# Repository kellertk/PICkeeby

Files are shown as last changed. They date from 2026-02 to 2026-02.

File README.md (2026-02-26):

# PICkeeby

PS/2 Keyboard/Mouse Controller for Homebrew Computers

## Overview

PICkeeby emulates an i8042 keyboard controller, bridging PS/2 devices to a host
computer's I/O bus. It supports both 6502 and Z80 bus timing via a mode jumper,
and handles two PS/2 ports (keyboard and mouse) simultaneously.

The name is a nod to PIC's origin as "Peripheral Interface Controller" -- using
a small microcontroller for I/O duties is a time-honored tradition in computer
design.

## Hardware

- **MCU:** PIC16F18344 at 32 MHz (internal oscillator)
- **GAL:** ATF22V10C for address decoding, status flags (OBF/IBF), A0
  registration, and IRQ generation
- **Latches:** 74AHCT574 (output) and 74AHCT373 (input) for bus interfacing
- **Inverter:** 74AHCT1G14 derives the GAL register clock from the bus clock

Accent on the "homebrew" -- this is a through-hole design on a two-layer PCB.
Accent on the "HC" -- the bus interface is 5V TTL compatible.

### Bus Compatibility

The MODE jumper selects between:

- **6502 mode:** active-high clock (PHI2), active-high R/W
- **Z80 mode:** active-low /WR, active-low /RD

No minimum bus speed -- the design supports fully static operation. Maximum bus
speed is approximately 33 MHz (limited by GAL propagation delay).

## Building

Requires XC8 (Microchip C compiler) and galette (PLD assembler). Run
`./configure` (or `.\configure.ps1` on Windows) first to detect tools and
generate `config.mk`.

```shell
make              # Build firmware + PLD
make firmware     # Build PIC firmware only
make pld          # Build GAL/PLD only
make lint         # Lint markdown files
make flash        # Flash firmware via MPLAB IPE
make flash-pld    # Flash GAL via minipro
```

## Theory of Operation

The host computer sees two I/O ports at consecutive addresses:

- **Port 0x60 (A0=0):** Data register (read/write)
- **Port 0x64 (A0=1):** Status register (read) / Command register (write)

This matches the standard i8042 keyboard controller interface.

### Data Flow

**PS/2 device to host:** PS/2 clock edges trigger an interrupt-on-change ISR
that shifts in scan code bytes. The i8042 emulation layer queues them for the
host. When the output latch is free, a byte is clocked into the 74HCT574 and OBF
(Output Buffer Full) is set in the GAL, asserting /IRQ.

**Host to PS/2 device:** The host writes to the data or command register. The
GAL captures IBF (Input Buffer Full) and A0 on the bus clock edge. The PIC polls
IBF, reads the byte from the 74HCT373 input latch, and routes it through the
i8042 command processor.

### i8042 Emulation

Supports the standard command set: read/write command byte, port enable/disable,
self-test, port test, write to auxiliary device, and read/write of 32 bytes of
EEPROM-backed internal RAM. Scan code translation and A20 gate control are not
implemented.

## Documentation

- [Firmware Design](src/FIRMWARE.md) -- module details, state machines, pin
  assignments, timing
- [Hardware Design](hardware/HARDWARE.md) -- schematic walkthrough, GAL
  equations, connector pinouts

## License

This work is licensed under [CC BY-NC-SA 4.0](LICENSE). This license does not
permit commercial use.

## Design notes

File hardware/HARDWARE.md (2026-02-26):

# PICkeeby Hardware

## Overview

**Architecture:**

```text
                          HOST BUS (6502 or Z80)
                      D0-D7  A0  /CS  SIG1  SIG2
                        |     |   |    |     |
        +---------------+-----+---+----+-----+-----------+
        |               |         |          |           |
        |               |         |     +----+----+      |
        |               |         |     | U5:     |      |
        |               |         |     | 1G14    |      |
        |               |         |     +----+----+      |
        |               |         |          | /SIG2     |
        |    +----------+---------+----------+-----+     |
        |    |       U4: ATF22V10C GAL             |     |
        |    |   (Decoder + Status + OBF/IBF)      |     |
        |    +----+--------+----------+------------+     |
        |         |        |          |                  |
        |     /RD_DATA  LED_STATUS  Signals              |
        |         |        |                             |
+-------+----+    |    +===+===+           +-------------+-------+
| U2: 574    |    |    | (GAL) |           | U3: 373             |
| Output     |<---+    | Status|           | Input               |
| Latch      |         | Buffer|           | Latch               |
+-----+------+         +===+===+           +----------+----------+
      |                    |                          |
      | Q                  |                          | Q
      |                    |                          |
      +--------IDATA-------+----------IDATA----------+
                           |
                        +--+--+
                        | U1  |
                        | PIC |
                        +--+--+
                         /   \
                   PS/2      PS/2
                   Port 1    Port 2
```

---

## Components (4 ICs)

| Ref | Part | Function |
| --- | --- | --- |
| U1  | PIC16F18344-I/P | Main controller (dual PS/2) |
| U2  | 74AHCT574 | Output Latch (PIC → Host) |
| U3  | 74AHCT373 | Input Latch (Host → PIC) |
| U4  | ATF22V10C-15PU  | Address Decoder / Status Flags / Mode Logic |
| U5  | 74AHCT1G14 | Schmitt-trigger inverter (SIG2 → /SIG2) |

### Other Components

| Ref | Part | Function |
| --- | --- | --- |
| C1 | 1µF | U1 decoupling |
| C2 | 1µF | U2 decoupling |
| C3 | 1µF | U3 decoupling |
| C4 | 1µF | U4 decoupling |
| C5 | 1µF | U5 decoupling |
| R1, R2 | 4.7K | PS/2 Port 1 pull-ups |
| R3, R4 | 4.7K | PS/2 Port 2 pull-ups |
| R5-R8  | 300Ω | LED current limiters (×4) |
| R9 | 10K | MODE pull-up |
| D1 | 3mm LED (yellow) | Chip select indicator |
| D2 | 3mm LED (red) | Output buffer full indicator |
| D3 | 3mm LED (red) | Input buffer full indicator  |
| D4 | 3mm LED (green)  | Host polling indicator |
| J1 | Mini-DIN-6 | PS/2 Port 1 connector |
| J2 | Mini-DIN-6 | PS/2 Port 2 connector |
| J3 | 1x3 header | Mode select jumper |
| J4 | 1x15 header | Host bus connector |
| J5 | 1x6 header | ICSP programming header |

---

## Signal Reference

| Signal | Description |
| --- | --- |
| HDATA0-7 | Host data bus |
| IDATA0-7 | Internal data bus (between PIC and latches) |
| A0 | Address bit 0 from host (to GAL only) |
| A0_REG | Registered A0 from GAL (to PIC RA3) |
| SIG1 | R/W (6502) or /RD (Z80) |
| SIG2 | Φ2 (6502) or /WR (Z80) |
| /SIG2 | Inverted SIG2 from U5 (GAL registered clock) |
| /RD_DATA | Active LOW: host reading data port |
| LED_STATUS | Active HIGH: host reading status |
| /IRQ | Active LOW: interrupt to host |
| CLK_OUT | Rising edge: latch output data, set OBF |
| /OE_IN | Active LOW: enable input latch outputs |
| /IBF_CLR | Active LOW: clear IBF flag (held until next clock edge) |
| LE_IN | Latch Enable for input buffer: HIGH=transparent, LOW=latched |
| OBF | Output Buffer Full (status bit 0) |
| IBF | Input Buffer Full (status bit 1, registered) |
| /AUX | Auxiliary output buffer Full (status bit 5) - data from Port 2 |
| PS2_CLK1 | PS/2 Port 1 clock |
| PS2_DATA1  | PS/2 Port 1 data |
| PS2_CLK2 | PS/2 Port 2 clock |
| PS2_DATA2  | PS/2 Port 2 data |

---

## Bus Mode Selection (J3)

```text
J3: Mode Select (active LOW selects mode)
  [1-2] = 6502 mode (MODE pin LOW)
  [2-3] = Z80 mode  (MODE pin HIGH)

       6502    Z80
        ■──■    □       (shown: 6502 mode)
        1  2    3
           └────┘

Pin 1: GND
Pin 2: MODE (to U4)
Pin 3: +5V via 10K pull-up (R9)
```

### SIG1 and SIG2

These set the type of bus for the host: a 6502-style bus or a Z80-style bus.

| J4 Pin | Signal | 6502 Mode | Z80 Mode |
| --- | --- | --- | --- |
| 10 | SIG1 | R/W (HIGH=read)  | /RD (LOW=read)  |
| 12 | SIG2 | Φ2 (clock phase) | /WR (LOW=write) |

---

## Register Map

The A0 line selects between data port and status/command port. This is the same
as the i8042.

| A0  | R/W | Internal address decode result |
| --- | --- | --- |
| 0 | Read Data port | /RD_DATA |
| 0 | Write Data port | (write with A0=0) |
| 1 | Read Status port | LED_STATUS |
| 1 | Write Command port | (write with A0=1) |

---

## U1: PIC16F18344-I/P (DIP-20)

```text
              +-----------+
        +5V --|1        20|-- GND
       /AUX --|2        19|-- CLK_OUT
        IBF --|3        18|-- /OE_IN
         A0 --|4        17|-- /IBF_CLR
     IDATA0 --|5        16|-- IDATA1
     IDATA2 --|6        15|-- IDATA3
     IDATA4 --|7        14|-- IDATA5
     IDATA6 --|8        13|-- PS2_CLK1
     IDATA7 --|9        12|-- PS2_DATA1
  PS2_DATA2 --|10       11|-- PS2_CLK2
              +-----------+
```

### U1 Pin Connections

| Pin | Name | Signal | To |
| --- | ---- | --- | --- |
| 1 | VDD  | +5V | +5V, J5-2 |
| 2 | RA5  | /AUX | U4-8 |
| 3 | RA4  | IBF | U4-16 |
| 4 | RA3  | A0_REG | U4-14 |
| 5 | RC5  | IDATA0 | U2-2, U3-2 |
| 6 | RC4  | IDATA2 | U2-4, U3-6 |
| 7 | RC3  | IDATA4 | U2-6, U3-19 |
| 8 | RC6  | IDATA6 | U2-8, U3-15 |
| 9 | RC7  | IDATA7 | U2-9, U3-12 |
| 10  | RB7  | PS2_DATA2 | J2-1, R4 to +5V |
| 11  | RB6  | PS2_CLK2  | J2-5, R3 to +5V |
| 12  | RB5  | PS2_DATA1 | J1-1, R2 to +5V |
| 13  | RB4  | PS2_CLK1  | J1-5, R1 to +5V |
| 14  | RC2  | IDATA5 | U2-7, U3-16 |
| 15  | RC1  | IDATA3 | U2-5, U3-9 |
| 16  | RC0  | IDATA1 | U2-3, U3-5 |
| 17  | RA2  | /IBF_CLR  | U4-5 |
| 18  | RA1  | /OE_IN | U3-1, J5-5 (ICSPCLK) |
| 19  | RA0  | CLK_OUT | U4-9, U2-11, J5-4 (ICSPDAT) |
| 20  | VSS  | GND | GND, J5-3 |

**C1 (1µF):** Pin 1 to Pin 20

**A0 Latching:** The GAL captures A0 into a registered output (A0_REG) on the
falling edge of PHI2 (6502) or falling edge of /WR (Z80), using the /SIG2 clock
from U5. The PIC reads A0_REG directly from RA3 to distinguish between data
register writes (A0=0) and command register writes (A0=1). This replaces the
previous CLC1-based approach and provides hundreds of nanoseconds of setup
margin for A0 capture.

## U2: 74AHCT574 - Output Latch (SOIC-20)

PIC writes scan codes here. Rising edge of CLK_OUT latches data. Host reads when
/RD_DATA enables outputs.

```text
           +-----------+
/RD_DATA --|1        20|-- +5V
  IDATA0 --|2        19|-- HDATA0
  IDATA1 --|3        18|-- HDATA1
  IDATA2 --|4        17|-- HDATA2
  IDATA3 --|5        16|-- HDATA3
  IDATA4 --|6        15|-- HDATA4
  IDATA5 --|7        14|-- HDATA5
  IDATA6 --|8        13|-- HDATA6
  IDATA7 --|9        12|-- HDATA7
     GND --|10       11|-- ←CLK_OUT
           +-----------+
```

### U2 Pin Connections

| Pin | Name | Signal | To |
| --- | ---- | --- | --- |
| 1 | OEB  | /RD_DATA | U4-23 |
| 2 | D0 | IDATA0 | U1-5, U3-2 |
| 3 | D1 | IDATA1 | U1-16, U3-5 |
| 4 | D2 | IDATA2 | U1-6, U3-6 |
| 5 | D3 | IDATA3 | U1-15, U3-9 |
| 6 | D4 | IDATA4 | U1-7, U3-19 |
| 7 | D5 | IDATA5 | U1-14, U3-16 |
| 8 | D6 | IDATA6 | U1-8, U3-15 |
| 9 | D7 | IDATA7 | U1-9, U3-12 |
| 10  | GND  | GND | GND |
| 11  | CLK  | CLK_OUT  | U1-19, U4-9 |
| 12  | Q7 | HDATA7 | J4-8, U3-13 |
| 13  | Q6 | HDATA6 | J4-7, U3-14 |
| 14  | Q5 | HDATA5 | J4-6, U3-17, U4-21 |
| 15  | Q4 | HDATA4 | J4-5, U3-18 |
| 16  | Q3 | HDATA3 | J4-4, U3-8 |
| 17  | Q2 | HDATA2 | J4-3, U3-7 |
| 18  | Q1 | HDATA1 | J4-2, U3-4, U4-18  |
| 19  | Q0 | HDATA0 | J4-1, U3-3, U4-19  |
| 20  | VCC  | +5V | +5V |

**C2 (1µF):** Pin 20 to Pin 10

---

## U3: 74AHCT373 - Input Latch (SOIC-20)

Host writes commands here. Transparent when LE=HIGH, latches when LE goes LOW.

```text
         +-----------+
/OE_IN --|1        20|-- +5V
IDATA0 --|2        19|-- IDATA4
HDATA0 --|3        18|-- HDATA4
HDATA1 --|4        17|-- HDATA5
IDATA1 --|5        16|-- IDATA5
IDATA2 --|6        15|-- IDATA6
HDATA2 --|7        14|-- HDATA6
HDATA3 --|8        13|-- HDATA7
IDATA3 --|9        12|-- IDATA7
   GND --|10       11|-- LE_IN
         +-----------+
```

### U3 Pin Connections

| Pin | Name | Signal | To |
| --- | ---- | --- | --- |
| 1 | OEB  | /OE_IN | U1-18 |
| 2 | Q0 | IDATA0 | U1-5, U2-2 |
| 3 | D0 | HDATA0 | J4-1, U2-19, U4-19 |
| 4 | D1 | HDATA1 | J4-2, U2-18, U4-18 |
| 5 | Q1 | IDATA1 | U1-16, U2-3 |
| 6 | Q2 | IDATA2 | U1-6, U2-4 |
| 7 | D2 | HDATA2 | J4-3, U2-17 |
| 8 | D3 | HDATA3 | J4-4, U2-16 |
| 9 | Q3 | IDATA3 | U1-15, U2-5 |
| 10  | GND  | GND | GND |
| 11  | LE | LE_IN  | U4-20 |
| 12  | Q4 | IDATA7 | U1-9, U2-9 |
| 13  | D4 | HDATA7 | J4-8, U2-12 |
| 14  | D5 | HDATA6 | J4-7, U2-13 |
| 15  | Q5 | IDATA6 | U1-8, U2-8 |
| 16  | Q6 | IDATA5 | U1-14, U2-7 |
| 17  | D6 | HDATA5 | J4-6, U2-14, U4-21 |
| 18  | D7 | HDATA4 | J4-5, U2-15 |
| 19  | Q7 | IDATA4 | U1-7, U2-6 |
| 20  | VCC  | +5V | +5V |

**C3 (1µF):** Pin 20 to Pin 10

---

## U4: ATF22V10C - GAL (DIP-24)

Combines address decoder, status buffer, mode-switching logic, and buffer flags.
Pin 1 is the registered clock input, driven by /SIG2 from U5. IBF and A0_REG are
registered outputs clocked on /SIG2 rising edge (= SIG2 falling edge). OBF is a
combinational SR-latch. The GAL's asynchronous reset (AR) is wired to /IBF_CLR,
allowing the PIC to clear IBF (and A0_REG) immediately without waiting for a
clock edge.

```text
           +-----------+
   /SIG2 --|1        24|-- +5V
    MODE --|2        23|-- /RD_DATA
      A0 --|3        22|-- LED_STATUS
    SIG1 --|4        21|-- HDATA5
/IBF_CLR --|5        20|-- LE_IN
    SIG2 --|6        19|-- HDATA0
     /CS --|7        18|-- HDATA1
    /AUX --|8        17|-- OBF
 CLK_OUT --|9        16|-- IBF
         x-|10       15|-- /IRQ
         x-|11       14|-- A0_REG
     GND --|12       13|-- GND (/OE)
           +-----------+
```

### U4 Pin Connections

| Pin | Name | Signal | To |
| --- | ---- | --- | --- |
| 1 | CLK  | /SIG2 | U5 output |
| 2 | I | MODE | J3-2 |
| 3 | I | A0 | J4-9 |
| 4 | I | SIG1 | J4-10 |
| 5 | I | /IBF_CLR | U1-17 |
| 6 | I | SIG2 | J4-12, U5 input |
| 7 | I | /CS | J4-11, R5 to D1 |
| 8 | I | /AUX | U1-2 |
| 9 | I | CLK_OUT | U1-19, U2-11 |
| 10  | I | nc | GND |
| 11  | I | nc | GND |
| 12  | GND  | GND | GND |
| 13  | I/O  | /OE | GND (always enabled) |
| 14  | I/O  | A0_REG | U1-4 |
| 15  | I/O  | /IRQ | J4-13 |
| 16  | I/O  | IBF | U1-3, R7 to D3 anode |
| 17  | I/O  | OBF | R6 to D2 anode |
| 18  | I/O  | HDATA1 | J4-2, U2-18, U3-4 |
| 19  | I/O  | HDATA0 | J4-1, U2-19, U3-3 |
| 20  | I/O  | LE_IN | U3-11 |
| 21  | I/O  | HDATA5 | J4-6, U2-14, U3-14 |
| 22  | I/O  | LED_STATUS | R8 to D4 anode |
| 23  | I/O  | /RD_DATA | U2-1 |
| 24  | VCC  | +5V | +5V |

**C4 (1µF):** Pin 24 to Pin 12

---

## U5: 74AHCT1G14 - Schmitt-Trigger Inverter (SOT-23-5)

Inverts SIG2 to produce /SIG2 for the GAL registered clock input. The Schmitt
trigger provides clean edges from the host bus clock/write signal.

| Pin | Name | Signal | To |
| --- | ---- | --- | ----- |
| 1 | A | SIG2 | J4-12 |
| 2 | GND  | GND | GND |
| 3 | Y | /SIG2  | U4-1  |
| 5 | VCC  | +5V | +5V |

**C5 (1µF):** Pin 5 to Pin 2

---

## J1: PS/2 Port 1 Connector (Mini-DIN-6)

Female, front view:

```text
       5   6
      3     4
        1 2
```

| Pin | Signal | To |
| --- | --- | --- |
| 1 | PS2_DATA1 | U1-12, R2 to +5V |
| 3 | GND | GND |
| 4 | +5V | +5V |
| 5 | PS2_CLK1  | U1-13, R1 to +5V |

---

## J2: PS/2 Port 2 Connector (Mini-DIN-6)

Female, front view:

```text
       5   6
      3     4
        1 2
```

| Pin | Signal | To |
| --- | --- | --- |
| 1 | PS2_DATA2 | U1-10, R4 to +5V |
| 3 | GND | GND |
| 4 | +5V | +5V |
| 5 | PS2_CLK2  | U1-11, R3 to +5V |

---

## J3: Mode Select (1x3 Header)

| Pin | Signal | To |
| --- | --- | --- |
| 1 | GND | GND |
| 2 | MODE | U4-2 |
| 3 | +5V | R9 (10K) to +5V |

**Jumper Position:**

- Pins 1-2: 6502 mode (MODE = LOW)
- Pins 2-3: Z80 mode (MODE = HIGH via R9)

---

## J4: Host Connector (1x15 Header)

```text
  +-+-+-+-+-+-+-+-+-+-+-+-+-+-+-+
  |1|2|3|4|5|6|7|8|9|A|B|C|D|E|F|
  +-+-+-+-+-+-+-+-+-+-+-+-+-+-+-+
   D D D D D D D D A S / S / + G
   0 1 2 3 4 5 6 7 0 1 C 2 I 5 N
                       S   R V D
                           Q
```

| Pin | Signal | 6502 | Z80  | To |
| --- | --- | ---- | ---- | --- |
| 1 | D0 | D0 | D0 | HDATA0: U2-19, U3-3, U4-19  |
| 2 | D1 | D1 | D1 | HDATA1: U2-18, U3-4, U4-18  |
| 3 | D2 | D2 | D2 | HDATA2: U2-17, U3-7 |
| 4 | D3 | D3 | D3 | HDATA3: U2-16, U3-8 |
| 5 | D4 | D4 | D4 | HDATA4: U2-15, U3-18 |
| 6 | D5 | D5 | D5 | HDATA5: U2-14, U3-17, U4-21 |
| 7 | D6 | D6 | D6 | HDATA6: U2-13, U3-14 |
| 8 | D7 | D7 | D7 | HDATA7: U2-12, U3-13 |
| 9 | A0 | A0 | A0 | U4-3 |
| 10  | SIG1 | R/W  | /RD  | U4-4 |
| 11  | /CS | /CS  | /CS  | U4-7, R5 to D1 |
| 12  | SIG2 | Φ2 | /WR  | U4-6, U5-1 |
| 13  | /IRQ | /IRQ | /INT | U4-15 |
| 14  | +5V | +5V  | +5V  | +5V |
| 15  | GND | GND  | GND  | GND |

---

## J5: ICSP Header (1x6)

Standard Microchip ICSP pinout:

```text
  +-+-+-+-+-+-+
  |1|2|3|4|5|6|
  +-+-+-+-+-+-+
   M V G P P n
   C D S G G c
   L D S D C
   R
```

| Pin | Signal | To |
| --- | --- | --- |
| 1 | MCLR/VPP | nc (active LVP mode) |
| 2 | VDD | +5V |
| 3 | VSS | GND |
| 4 | ICSPDAT  | U1-19 (RA0/CLK_OUT)  |
| 5 | ICSPCLK  | U1-18 (RA1//OE_IN) |
| 6 | nc | - |

**Note:** The PIC uses Low-Voltage Programming (LVP) mode with MCLR disabled.
RA3 is repurposed as the A0_REG input from the GAL. Pin 1 of the ICSP header is
not connected; programming uses only ICSPDAT/ICSPCLK. Do not use high-voltage
programming mode.

---

## LEDs: Status Indicators

| LED | Pin | Signal | Color  | Indicates |
| --- | ----- | --- | --- | --- |
| D1  | J4-11 | /CS | Yellow | Chip selected (via R5) |
| D2  | U4-17 | OBF | Red | PIC has data waiting for host |
| D3  | U4-16 | IBF | Red | Host has sent command to PIC |
| D4  | U4-22 | LED_STATUS | Green  | Host is polling status register |

---

## BOM (5 ICs + Support)

### ICs

| Ref | Part | Package  | Function |
| --- | --- | --- | --- |
| U1  | PIC16F18344-I/P | DIP-20 | Controller (dual PS/2) |
| U2  | 74AHCT574 | SOIC-20  | Output Latch |
| U3  | 74AHCT373 | SOIC-20  | Input Latch |
| U4  | ATF22V10C-xxPU  | DIP-24 | GAL (Decoder/Status/Flags) |
| U5  | 74AHCT1G14 | SOT-23-5 | Schmitt inverter (SIG2→/SIG2) |

### Passive Components

| Ref | Value | Package | Function |
| --- | ----- | --- | --- |
| C1-C5  | 1µF | Ceramic | Decoupling (×5) |
| R1, R2 | 4.7K  | 1/4W | PS/2 Port 1 pull-ups |
| R3, R4 | 4.7K  | 1/4W | PS/2 Port 2 pull-ups |
| R5-R8  | 300Ω  | 1/4W | LED current limit (×4) |
| R9 | 10K | 1/4W | MODE pull-up |

### Connectors & Indicators

| Ref | Part | Function |
| --- | --- | --- |
| J1  | Mini-DIN-6 female | PS/2 Port 1 |
| J2  | Mini-DIN-6 female | PS/2 Port 2 |
| J3  | 1×3 header + jumper | Mode select |
| J4  | 1×15 header | Host bus |
| J5  | 1×6 header | ICSP |
| D1  | 3mm LED (yellow) | Chip select |
| D2  | 3mm LED (red) | OBF |
| D3  | 3mm LED (red) | IBF |
| D4  | 3mm LED (green) | Status read |

---

## Data Flow

### PS/2 activity (Port 1)

1. PIC sets /AUX = LOW (data from Port 1)
2. PIC disables U3 outputs (/OE_IN=HIGH)
3. PIC drives IDATA0-7 with scan code
4. PIC pulses CLK_OUT HIGH
5. Rising edge latches into U2, sets OBF (in GAL), asserts /IRQ
6. Host reads data port → /RD_DATA clears OBF (async reset in GAL)

### PS/2 activity (Port 2)

1. PIC sets /AUX = HIGH (data from Port 2)
2. PIC disables U3 outputs (/OE_IN=HIGH)
3. PIC drives IDATA0-7 with scan code
4. PIC pulses CLK_OUT HIGH
5. Rising edge latches into U2, sets OBF (in GAL), asserts /IRQ
6. Host reads status → sees /AUX=1 (bit 5), knows data is from Port 2
7. Host reads data port → /RD_DATA clears OBF (async reset in GAL)

### Host sends command (6502 mode)

1. Host drives D0-D7 with command, sets A0, R/W=LOW
2. During Φ2 HIGH: LE_IN=HIGH (373 transparent, tracking data bus)
3. **Φ2 falls:** LE_IN→LOW (373 latches valid data). /SIG2 rises ~8ns later.
4. GAL clocks registered outputs: IBF captures write condition, A0_REG captures
   A0
5. PIC sees IBF=HIGH, reads A0_REG from RA3, enables U3 (/OE_IN=LOW), reads
   IDATA
6. PIC pulses /IBF_CLR LOW, triggering GAL async reset (clears IBF immediately)

### Host sends command (Z80 mode)

1. Host drives D0-D7 with command, sets A0, /CS=LOW
2. **/WR falls:** /SIG2 rises ~8ns later. GAL clocks: IBF=1, A0_REG captures A0.
   LE_IN=HIGH (373 transparent, tracking data bus)
3. Z80 drives data during /WR LOW. 373 tracks.
4. **/WR rises:** LE_IN→LOW (373 latches data)
5. PIC sees IBF=HIGH, reads A0_REG from RA3, enables U3 (/OE_IN=LOW), reads
   IDATA
6. PIC pulses /IBF_CLR LOW, triggering GAL async reset (clears IBF immediately)

### Host reads status (both modes)

1. Host performs read with A0=1
2. LED_STATUS enables GAL tri-state outputs on HDATA0, HDATA1, HDATA5
3. GAL drives OBF→D0, IBF→D1, /AUX→D5

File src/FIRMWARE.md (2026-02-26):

# PICkeeby Firmware Design

## Overview

PICkeeby emulates an i8042 keyboard controller, bridging PS/2 devices to a host
computer's I/O bus. The firmware runs on a PIC16F18344 at 32 MHz.

```text
+-------------+       +-------------+       +-------------+
|   PS/2      |       |             |       |    Host     |
|  Keyboard   |<----->|   PICkeeby  |<----->|   Computer  |
|   / Mouse   |       |             |       |  (6502/Z80) |
+-------------+       +-------------+       +-------------+
     Port 1/2           PIC16F18344          via latches
```

## Architecture

The firmware is organized into four modules:

| Module | File | Purpose |
| --- | --- | --- |
| PS/2 Protocol | ps2.c/h | Bidirectional PS/2 communication |
| Host Interface  | host.c/h  | Latch control and data transfer |
| i8042 Emulation | i8042.c/h | Command processing and port management |
| Main | main.c | Initialization and main loop |

### Data Flow

**Device → Host (scan codes):**

```text
PS/2 Device → ps2_clock_isr → rx_queue → i8042_task → host_send_data → output_queue → host_pump_output → 74HCT574 → Host
```

**Host → Device (commands):**

```text
Host → 74HCT373 → IBF → host_read_input → i8042_process_byte → ps2_tx_write → tx_queue → ps2_task → PS/2 Device
```

---

## Module Details

### ps2.c — PS/2 Protocol Layer

Implements the PS/2 protocol using bit-banged I/O with interrupt-driven clock
handling.

**State Machine:**

```text
                    start bit (DATA=0)
        IDLE ─────────────────────────────> RX
          │                                  │
          │                                  │ 11 clocks
          │                                  ▼
          │<─────────────────────────────────┘
          │
          │  ps2_task() initiates TX
          ▼
         TX ──────────────────────────────> TX_ACK
                   11 clocks                  │
                                              │ device ACK
                                              ▼
                                            IDLE
```

**Receive (device-initiated):**

1. Device pulls DATA low (start bit)
2. ISR detects start, enters RX state
3. 8 data bits shifted in on falling clock edges
4. Parity bit checked
5. Stop bit validated
6. Byte queued if valid

**Transmit (host-initiated):**

1. `ps2_task()` detects pending TX data
2. PIC holds CLK low for 150µs (request-to-send)
3. PIC pulls DATA low (start bit)
4. PIC releases CLK, device clocks out bits
5. ISR sends 8 data bits + parity + stop
6. Device sends ACK (pulls DATA low)

**Functions:**

- `ps2_clock_isr(port)` -- Called from ISR on clock falling edge
- `ps2_task()` -- Initiates pending transmissions, checks for timeouts
- `ps2_inhibit(port, inhibit)` -- Enable/disable port communication

**Timeout Recovery:** If no clock activity occurs for ~2ms while in RX or TX
state, the port resets to IDLE. This prevents permanent data misalignment from
dropped clock pulses.

### host.c — Host Bus Interface

Manages the 74HCT574 output latch and 74HCT373 input latch.

**A0 Latching:** The GAL captures A0 into a registered output (A0_REG on pin 14)
on the /SIG2 clock edge — the falling edge of PHI2 (6502) or the falling edge of
WRB (Z80). The PIC reads A0_REG directly from RA3 to distinguish command
register writes (A0=1) from data register writes (A0=0). This provides hundreds
of nanoseconds of setup margin since A0 is stable for the entire active bus
phase.

**Output Flow (PIC → Host):**

```text
1. Set AUXB (port identifier)
2. Drive IDATA bus with data byte
3. Pulse CLK_OUT high → latches data, sets OBF in GAL
4. Host reads data register (A0=0) → clears OBF
```

**Input Flow (Host → PIC):**

```text
1. Host writes to data or command register
2. On bus clock edge: GAL registers IBF=1 and captures A0 into A0_REG
3. PIC polls IBF_GetValue()
4. When IBF=1: read A0_REG from RA3 (stable, held by GAL D-FF)
5. Switch IDATA to input, enable latch outputs
6. Read byte from IDATA_PORT
7. Disable latch outputs, restore IDATA to output
8. Pulse IBF_CLRB low to clear IBF (GAL async reset, immediate)
```

**Functions:**

- `host_init()` -- Initialize latches and control signals
- `host_send_data(data, aux)` -- Queue byte for host
- `host_pump_output()` -- Transfer one queued byte to output latch
- `host_ibf_active()` -- Check if host has written data
- `host_get_a0()` -- Read A0_REG from RA3 (GAL-registered)
- `host_read_input()` -- Read and acknowledge host write

### i8042.c — Controller Emulation

Emulates i8042 command set (without A20 gate or system reset).

**Command Byte (internal register, read via 0x20, write via 0x60):**

```text
Bit 6: XLAT    - Scan code translation (stored but not implemented)
Bit 5: AUX_DIS - Disable auxiliary port (mouse)
Bit 4: KBD_DIS - Disable keyboard port
Bit 2: SYS     - System flag
Bit 1: AUX_INT - Auxiliary interrupt enable
Bit 0: KBD_INT - Keyboard interrupt enable
```

**Supported Commands:**

| Command | Function |
| --- | --- |
| 0x20 | Read command byte |
| 0x21-0x3F | Read EEPROM[1-31] |
| 0x60 | Write command byte |
| 0x61-0x7F | Write EEPROM[1-31] |
| 0xA7 | Disable auxiliary port |
| 0xA8 | Enable auxiliary port |
| 0xA9 | Test auxiliary port (returns 0x00)  |
| 0xAA | Controller self-test (returns 0x55) |
| 0xAB | Test keyboard port (returns 0x00) |
| 0xAD | Disable keyboard port |
| 0xAE | Enable keyboard port |
| 0xC0 | Read input port |
| 0xD0 | Read output port |
| 0xD1 | Write output port (ignored) |
| 0xD2 | Write keyboard output buffer |
| 0xD3 | Write auxiliary output buffer |
| 0xD4 | Write to auxiliary device |
| 0xFE | Reset keyboard controller |

**Command vs Data Routing:**

The hardware provides A0 distinction via the GAL-registered A0_REG output. When
IBF is set, the PIC reads A0_REG from RA3 to determine if the byte is a command
(A0=1) or data (A0=0). Additionally, commands are identified by value:

- Bytes in command ranges (0x20-0x3F, 0x60-0x7F, 0xA7-0xAF, etc.) -> processed
  as commands
- Other bytes -> forwarded to keyboard via PS/2

Multi-byte commands use a pending state machine:

```c
typedef enum {
    PEND_NONE,
    PEND_CMD_BYTE,    // Next byte is command byte data
    PEND_OUTPUT_PORT, // Next byte is output port data
    PEND_KBD_OUTPUT,  // Next byte goes to keyboard output buffer
    PEND_AUX_OUTPUT,  // Next byte goes to aux output buffer
    PEND_AUX_DEVICE,  // Next byte goes to aux device via PS/2
    PEND_EEPROM       // Next byte goes to EEPROM
} pending_t;
```

**EEPROM Storage:** The i8042 internal RAM commands (0x20-0x3F read, 0x60-0x7F
write) are mapped to the PIC's EEPROM. Address 0 remains the command byte;
addresses 1-31 provide 31 bytes of nonvolatile storage accessible to the host.

### main.c

**Main Loop:**

```c
while (1) {
    ps2_task();        // Initiate pending PS/2 transmissions
    i8042_task();      // Forward PS/2 RX data to host queue

    if (host_data_pending()) {
        host_pump_output();  // Send one byte to output latch
    }

    if (host_ibf_active()) {
        bool is_cmd = host_get_a0();
        uint8_t byte = host_read_input();
        i8042_process_byte(byte, is_cmd);
    }
}
```

---

## Pin Assignments

| Pin | Port | Function  | Direction |
| --- | ---- | --- | --- |
| 19  | RA0  | CLK_OUT | Output |
| 18  | RA1  | OE_INB | Output |
| 17  | RA2  | IBF_CLRB  | Output |
| 4 | RA3  | A0_REG | Input (from GAL pin 14) |
| 3 | RA4  | IBF | Input (from GAL pin 16) |
| 2 | RA5  | AUXB | Output |
| 13  | RB4  | PS2_CLK1  | Bidirectional (open-drain) |
| 12  | RB5  | PS2_DATA1 | Bidirectional (open-drain) |
| 11  | RB6  | PS2_CLK2  | Bidirectional (open-drain) |
| 10  | RB7  | PS2_DATA2 | Bidirectional (open-drain) |
| 16  | RC0  | IDATA1 | Bidirectional |
| 15  | RC1  | IDATA3 | Bidirectional |
| 14  | RC2  | IDATA5 | Bidirectional |
| 7 | RC3  | IDATA4 | Bidirectional |
| 6 | RC4  | IDATA2 | Bidirectional |
| 5 | RC5  | IDATA0 | Bidirectional |
| 8 | RC6  | IDATA6 | Bidirectional |
| 9 | RC7  | IDATA7 | Bidirectional |

---

## Interrupt Handling

Single ISR handles both PS/2 ports via interrupt-on-change:

```c
void __interrupt() ISR(void) {
    if (PIR0bits.IOCIF) {
        if (IOCBFbits.IOCBF4) {
            IOCBFbits.IOCBF4 = 0;
            ps2_clock_isr(PS2_PORT1);
        }
        if (IOCBFbits.IOCBF6) {
            IOCBFbits.IOCBF6 = 0;
            ps2_clock_isr(PS2_PORT2);
        }
    }
}
```

IOC triggers on falling edge of PS/2 clock (IOCBN = 0x50).

---

## Timing Considerations

**PS/2 Clock:** 10-16.7 kHz (60-100 µs per bit)

- ISR must complete within ~30 µs to catch next edge
- At 32 MHz, ~960 instruction cycles available

**Host Read Rate:** Depends on host software polling interval

- Output queue (32 entries) buffers scan codes from PS/2 devices
- If host doesn't read before queue fills, new data is dropped
- OBF flag in status register tells host when data is waiting
- To avoid output buffer overrun, the host should read data once every 12.5 ms
  on average
- The output buffer can hold approximately 500 ms of keystrokes from a fast
  typist before dropping data

**Host Write Rate:** Not critical

- PIC polls IBF in main loop, typically sub-millisecond response
- Host must wait for IBF to clear before writing next byte

**TX Request-to-Send:** 150 µs clock inhibit before transmission

---

## Limitations

1. **No scan code translation** — XLAT bit is stored but Set 2 → Set 1
   translation is not implemented

2. **No A20 control** — 0xD1 output port writes are acknowledged but A20 gate
   bit is ignored

3. **Single-byte lookahead** — Multi-byte PS/2 sequences (e.g., extended keys)
   are interpreted by the host

4. **LVP programming only** — MCLR is disabled; do not use high-voltage
   programming mode

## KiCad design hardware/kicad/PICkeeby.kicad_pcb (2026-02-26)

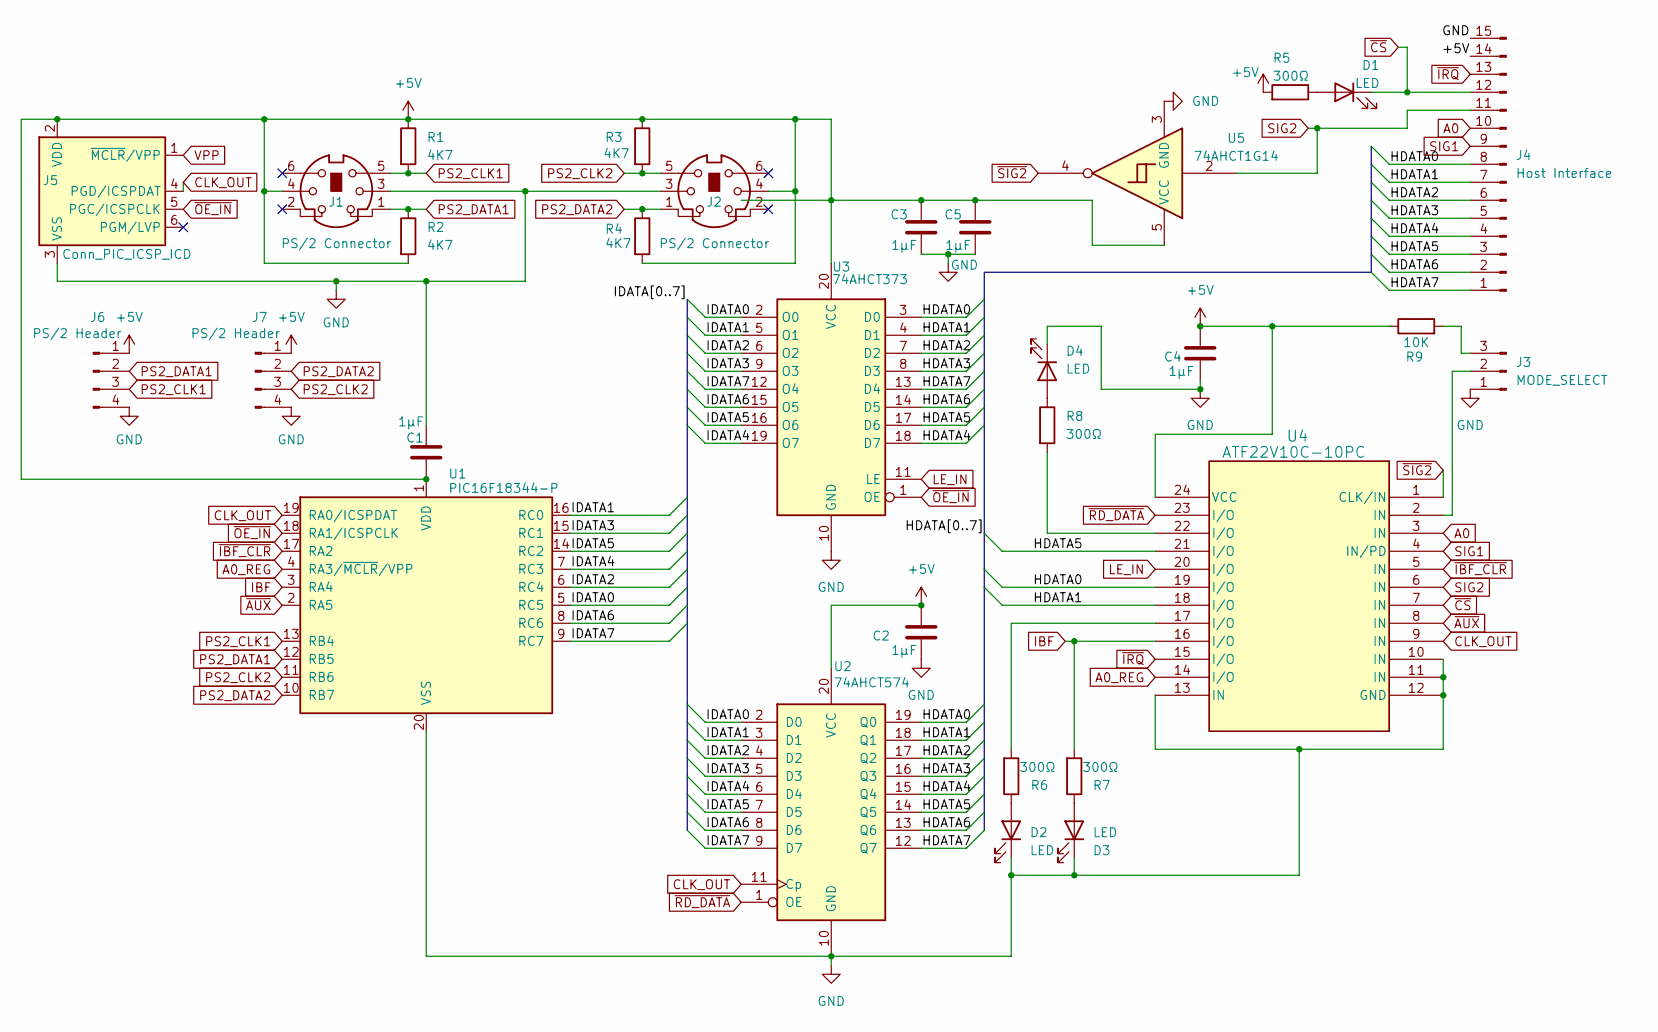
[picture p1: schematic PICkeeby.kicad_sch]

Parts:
C1, C2, C3, C4, C5: 1µF; C_0805_2012Metric_Pad1.18x1.45mm_HandSolder
D1, D2, D3, D4: LED; LED_D3.0mm_FlatTop
J1, J2: PS/2 Connector; CUI_MD-60SM
J3: MODE_SELECT; PinHeader_1x03_P2.54mm_Vertical
J4: Host Interface; PinSocket_1x15_P2.54mm_Vertical
J5: Conn_PIC_ICSP_ICD; PinHeader_1x06_P2.54mm_Vertical
J6, J7: PS/2 Header; PinHeader_1x04_P2.54mm_Vertical
R1, R2, R3, R4: 4K7; R_0805_2012Metric_Pad1.20x1.40mm_HandSolder
R5, R6, R7, R8: 300Ω; R_0805_2012Metric_Pad1.20x1.40mm_HandSolder
R9: 10K; R_0805_2012Metric_Pad1.20x1.40mm_HandSolder
U1: PIC16F18344-P; DIP-20_W7.62mm_Socket_LongPads
U2: 74AHCT574; SOIC-20W_7.5x12.8mm_P1.27mm
U3: 74AHCT373; SOIC-20W_7.5x12.8mm_P1.27mm
U4: ATF22V10C-10PC; DIP-24_W7.62mm_Socket_LongPads
U5: 74AHCT1G14; SOT-23-5_HandSoldering

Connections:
+5V: C1.1, C2.1, C3.1, C4.1, C5.1, J1.4, J2.4, J4.14, J5.2 (VDD), J6.1, J7.1, R1.1, R2.2, R3.1, R4.2, R5.2, R9.1, U1.1 (VDD), U2.20 (VCC), U3.20 (VCC), U4.24 (VCC), U5.5 (VCC); also elsewhere on the board
/HDATA0: J4.8, U2.19 (Q0), U3.3 (D0), U4.19 (I/O)
/HDATA1: J4.7, U2.18 (Q1), U3.4 (D1), U4.18 (I/O)
/HDATA2: J4.6, U2.17 (Q2), U3.7 (D2)
/HDATA3: J4.5, U2.16 (Q3), U3.8 (D3)
/HDATA4: J4.4, U2.15 (Q4), U3.18 (D7)
/HDATA5: J4.3, U2.14 (Q5), U3.17 (D6), U4.21 (I/O)
/HDATA6: J4.2, U2.13 (Q6), U3.14 (D5)
/HDATA7: J4.1, U2.12 (Q7), U3.13 (D4)
/IDATA0: U1.5 (RC5), U2.2 (D0), U3.2 (O0)
/IDATA1: U1.16 (RC0), U2.3 (D1), U3.5 (O1)
/IDATA2: U1.6 (RC4), U2.4 (D2), U3.6 (O2)
/IDATA3: U1.15 (RC1), U2.5 (D3), U3.9 (O3)
/IDATA4: U1.7 (RC3), U2.6 (D4), U3.19 (O7)
/IDATA5: U1.14 (RC2), U2.7 (D5), U3.16 (O6)
/IDATA6: U1.8 (RC6), U2.8 (D6), U3.15 (O5)
/IDATA7: U1.9 (RC7), U2.9 (D7), U3.12 (O4)
A0: J4.10, U4.3 (IN)
A0_REG: U1.4 (RA3/~MCLR/VPP), U4.14 (I/O)
CLK_OUT: J5.4 (PGD/ICSPDAT), U1.19 (RA0/ICSPDAT), U2.11 (Cp), U4.9 (IN)
GND: C1.2, C2.2, C3.2, C4.2, C5.2, D2.1 (K), D3.1 (K), D4.1 (K), J1.3, J2.3, J3.1, J4.15, J5.3 (VSS), J6.4, J7.4, U1.20 (VSS), U2.10 (GND), U3.10 (GND), U4.10 (IN), U4.11 (IN), U4.12 (GND), U4.13 (IN), U5.3 (GND); also elsewhere on the board
IBF: R7.2, U1.3 (RA4), U4.16 (I/O)
LE_IN: U3.11 (LE), U4.20 (I/O)
unnamed: D1.2 (A), R5.1
unnamed: D2.2 (A), R6.1
unnamed: D3.2 (A), R7.1
unnamed: D4.2 (A), R8.1
unnamed: J3.2, U4.2 (IN)
unnamed: J3.3, R9.2
unnamed: R6.2, U4.17 (I/O)
unnamed: R8.2, U4.22 (I/O)
PS2_CLK1: J1.5, J6.3, R1.2, U1.13 (RB4)
PS2_CLK2: J2.5, J7.3, R3.2, U1.11 (RB6)
PS2_DATA1: J1.1, J6.2, R2.1, U1.12 (RB5)
PS2_DATA2: J2.1, J7.2, R4.1, U1.10 (RB7)
SIG1: J4.9, U4.4 (IN/PD)
SIG2: J4.11, U4.6 (IN), U5.2
VPP: J5.1 (~MCLR/VPP)
~AUX: U1.2 (RA5), U4.8 (IN)
~CS: D1.1 (K), J4.12, U4.7 (IN)
~IBF_CLR: U1.17 (RA2), U4.5 (IN)
~IRQ: J4.13, U4.15 (I/O)
~OE_IN: J5.5 (PGC/ICSPCLK), U1.18 (RA1/ICSPCLK), U3.1 (OE)
~RD_DATA: U2.1 (OE), U4.23 (I/O)
~SIG2: U4.1 (CLK/IN), U5.4

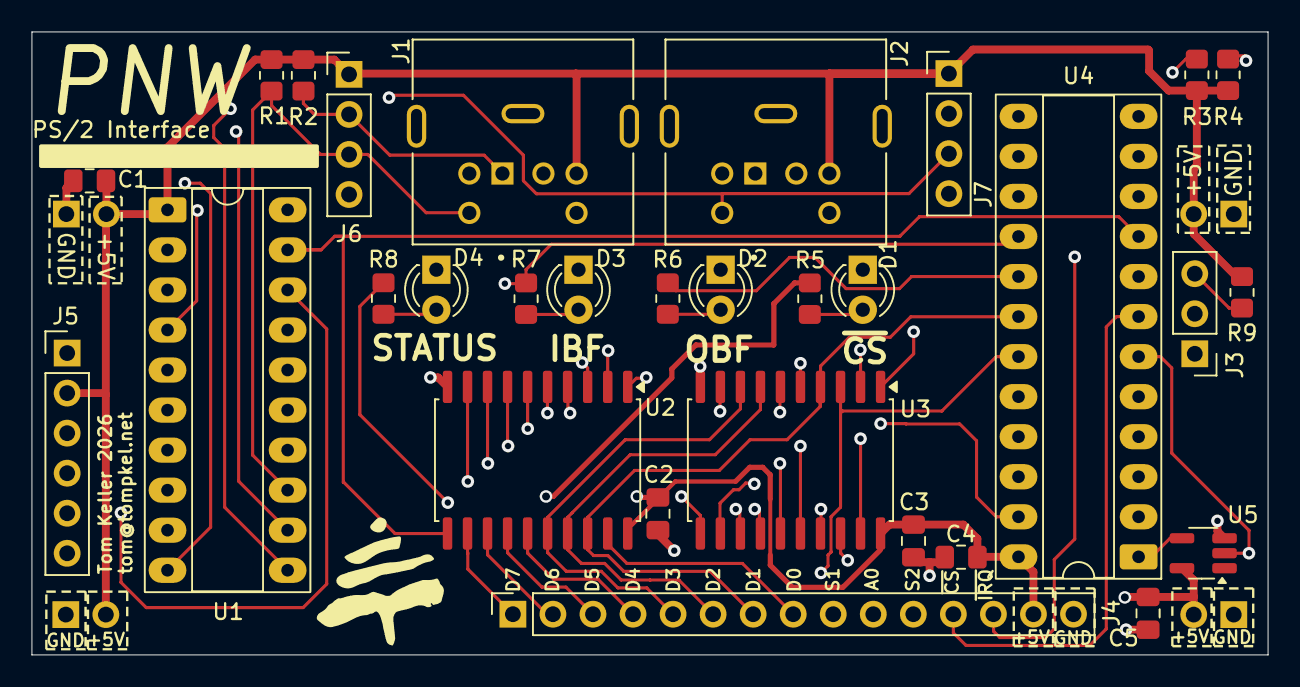
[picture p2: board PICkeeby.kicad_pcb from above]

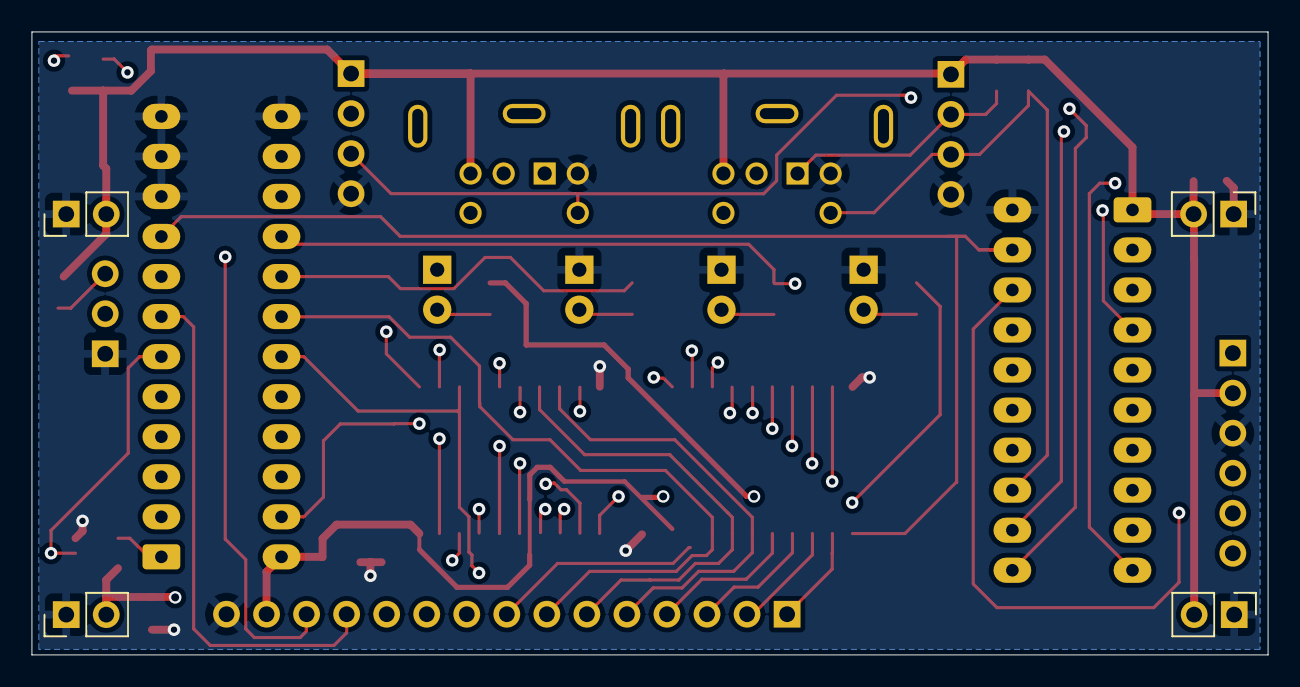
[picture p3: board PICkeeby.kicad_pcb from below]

Board: 4 copper layers, 78.4 x 39.5 mm, 34 parts (4 on the bottom side), 44 nets.

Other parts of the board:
x1, x2, x3, x4: PinHeader_1x02_P2.54mm_Vertical

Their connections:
+5V: x1.2, x2.2, x3.2, x4.2; also elsewhere on the board
GND: x1.1, x2.1, x3.1, x4.1; also elsewhere on the board

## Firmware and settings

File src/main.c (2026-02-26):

/**
 * PICkeeby - main.c
 * PS/2 Keyboard Controller for Homebrew Computers
 * i8042-compatible interface
 */

#include <xc.h>
#include <stdint.h>
#include <stdbool.h>
#include "pins.h"
#include "ps2.h"
#include "host.h"
#include "i8042.h"

// CONFIG1
#pragma config FEXTOSC = OFF    // External oscillator disabled
#pragma config RSTOSC = HFINT32 // Power up osc: HFINTOSC with OSCFRQ = 32 MHz
#pragma config CLKOUTEN = OFF   // CLKOUT disabled
#pragma config CSWEN = OFF      // Clock switch disabled
#pragma config FCMEN = ON       // Fail-safe clock monitor enabled

// CONFIG2
#pragma config MCLRE = OFF      // MCLR disabled, RA3 is digital input
#pragma config PWRTE = OFF      // Power-up timer disabled
#pragma config WDTE = OFF       // Watchdog disabled
#pragma config LPBOREN = OFF    // Low-power BOR disabled
#pragma config BOREN = ON       // Brown-out reset enabled
#pragma config BORV = HIGH      // Brown-out voltage trip point high

// CONFIG3
#pragma config PPS1WAY = ON     // PPS locked after one unlock
#pragma config STVREN = ON      // Stack overflow resets device

// CONFIG4
#pragma config WRT = OFF        // Flash write protection off
#pragma config LVP = ON         // Low-voltage programming enabled
#pragma config CP = OFF         // Code protection off
#pragma config CPD = OFF        // Data EEPROM protection off

static void clock_init(void) {
    OSCCON1 = (0 << _OSCCON1_NDIV_POSN) | (6 << _OSCCON1_NOSC_POSN);
    OSCFRQ = (6 << _OSCFRQ_HFFRQ_POSN);  // 32 MHz
}

static void pins_init(void) {
    // Set analog pins to digital
    ANSELA = 0x00;
    ANSELB = 0x00;
    ANSELC = 0x00;

    // RA0: CLK_OUT (output, push-pull)
    // RA1: OE_INB (output, push-pull)
    // RA2: IBF_CLRB (output, push-pull)
    // RA3: A0_REG (input from GAL, registered A0)
    // RA4: IBF (input from GAL, registered)
    // RA5: AUXB (output, push-pull)
    TRISA = 0x18;  // RA3, RA4 as inputs
    LATA = 0x06;   // IBF_CLRB high, OE_INB high (disable 373)
    ODCONA = 0x00;

    // RB4: PS2_CLK1 (bidirectional, open-drain)
    // RB5: PS2_DATA1 (bidirectional, open-drain)
    // RB6: PS2_CLK2 (bidirectional, open-drain)
    // RB7: PS2_DATA2 (bidirectional, open-drain)
    TRISB = 0xF0;
    LATB = 0x00;
    ODCONB = 0xF0;

    // RC0-7: IDATA bus (output to latches)
    TRISC = 0x00;
    LATC = 0x00;

    // IOC for PS/2 clock falling edges
    IOCBN = 0x50;  // Negative edge on RB4, RB6
    IOCBF = 0x00;

    // Enable IOC interrupt
    PIE0bits.IOCIE = 1;
}

void __interrupt() ISR(void) {
    if (PIR0bits.IOCIF) {
        if (IOCBFbits.IOCBF4) {
            IOCBFbits.IOCBF4 = 0;
            ps2_clock_isr(PS2_PORT1);
        }
        if (IOCBFbits.IOCBF6) {
            IOCBFbits.IOCBF6 = 0;
            ps2_clock_isr(PS2_PORT2);
        }
    }
}

int main(void) {
    clock_init();
    pins_init();
    ps2_init();
    host_init();
    i8042_init();

    // Enable interrupts
    INTCONbits.PEIE = 1;
    INTCONbits.GIE = 1;

    while (1) {
        ps2_task();
        i8042_task();

        // Pump output queue to host
        if (host_data_pending()) {
            host_pump_output();
        }

        // Check for host input
        if (host_ibf_active()) {
            bool is_cmd = host_get_a0();
            uint8_t byte = host_read_input();
            i8042_process_byte(byte, is_cmd);
        }
    }
}

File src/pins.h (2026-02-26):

/**
 * PICkeeby - pins.h
 * Pin definitions and macros
 */

#ifndef PINS_H
#define PINS_H

#include <xc.h>

#define _XTAL_FREQ 32000000UL

#define INPUT   1
#define OUTPUT  0
#define HIGH    1
#define LOW     0
#define ANALOG      1
#define DIGITAL     0
#define PULL_UP_ENABLED      1
#define PULL_UP_DISABLED     0

// RA0 - CLK_OUT
#define CLK_OUT_TRIS                 TRISAbits.TRISA0
#define CLK_OUT_LAT                  LATAbits.LATA0
#define CLK_OUT_PORT                 PORTAbits.RA0
#define CLK_OUT_WPU                  WPUAbits.WPUA0
#define CLK_OUT_OD                   ODCONAbits.ODCA0
#define CLK_OUT_ANS                  ANSELAbits.ANSA0
#define CLK_OUT_SetHigh()            do { LATAbits.LATA0 = 1; } while(0)
#define CLK_OUT_SetLow()             do { LATAbits.LATA0 = 0; } while(0)
#define CLK_OUT_Toggle()             do { LATAbits.LATA0 = ~LATAbits.LATA0; } while(0)
#define CLK_OUT_GetValue()           PORTAbits.RA0
#define CLK_OUT_SetDigitalInput()    do { TRISAbits.TRISA0 = 1; } while(0)
#define CLK_OUT_SetDigitalOutput()   do { TRISAbits.TRISA0 = 0; } while(0)
#define CLK_OUT_SetPullup()          do { WPUAbits.WPUA0 = 1; } while(0)
#define CLK_OUT_ResetPullup()        do { WPUAbits.WPUA0 = 0; } while(0)
#define CLK_OUT_SetPushPull()        do { ODCONAbits.ODCA0 = 0; } while(0)
#define CLK_OUT_SetOpenDrain()       do { ODCONAbits.ODCA0 = 1; } while(0)
#define CLK_OUT_SetAnalogMode()      do { ANSELAbits.ANSA0 = 1; } while(0)
#define CLK_OUT_SetDigitalMode()     do { ANSELAbits.ANSA0 = 0; } while(0)

// RA1 - OE_INB
#define OE_INB_TRIS                 TRISAbits.TRISA1
#define OE_INB_LAT                  LATAbits.LATA1
#define OE_INB_PORT                 PORTAbits.RA1
#define OE_INB_WPU                  WPUAbits.WPUA1
#define OE_INB_OD                   ODCONAbits.ODCA1
#define OE_INB_ANS                  ANSELAbits.ANSA1
#define OE_INB_SetHigh()            do { LATAbits.LATA1 = 1; } while(0)
#define OE_INB_SetLow()             do { LATAbits.LATA1 = 0; } while(0)
#define OE_INB_Toggle()             do { LATAbits.LATA1 = ~LATAbits.LATA1; } while(0)
#define OE_INB_GetValue()           PORTAbits.RA1
#define OE_INB_SetDigitalInput()    do { TRISAbits.TRISA1 = 1; } while(0)
#define OE_INB_SetDigitalOutput()   do { TRISAbits.TRISA1 = 0; } while(0)
#define OE_INB_SetPullup()          do { WPUAbits.WPUA1 = 1; } while(0)
#define OE_INB_ResetPullup()        do { WPUAbits.WPUA1 = 0; } while(0)
#define OE_INB_SetPushPull()        do { ODCONAbits.ODCA1 = 0; } while(0)
#define OE_INB_SetOpenDrain()       do { ODCONAbits.ODCA1 = 1; } while(0)
#define OE_INB_SetAnalogMode()      do { ANSELAbits.ANSA1 = 1; } while(0)
#define OE_INB_SetDigitalMode()     do { ANSELAbits.ANSA1 = 0; } while(0)

// RA2 - IBF_CLRB
#define IBF_CLRB_TRIS                 TRISAbits.TRISA2
#define IBF_CLRB_LAT                  LATAbits.LATA2
#define IBF_CLRB_PORT                 PORTAbits.RA2
#define IBF_CLRB_WPU                  WPUAbits.WPUA2
#define IBF_CLRB_OD                   ODCONAbits.ODCA2
#define IBF_CLRB_ANS                  ANSELAbits.ANSA2
#define IBF_CLRB_SetHigh()            do { LATAbits.LATA2 = 1; } while(0)
#define IBF_CLRB_SetLow()             do { LATAbits.LATA2 = 0; } while(0)
#define IBF_CLRB_Toggle()             do { LATAbits.LATA2 = ~LATAbits.LATA2; } while(0)
#define IBF_CLRB_GetValue()           PORTAbits.RA2
#define IBF_CLRB_SetDigitalInput()    do { TRISAbits.TRISA2 = 1; } while(0)
#define IBF_CLRB_SetDigitalOutput()   do { TRISAbits.TRISA2 = 0; } while(0)
#define IBF_CLRB_SetPullup()          do { WPUAbits.WPUA2 = 1; } while(0)
#define IBF_CLRB_ResetPullup()        do { WPUAbits.WPUA2 = 0; } while(0)
#define IBF_CLRB_SetPushPull()        do { ODCONAbits.ODCA2 = 0; } while(0)
#define IBF_CLRB_SetOpenDrain()       do { ODCONAbits.ODCA2 = 1; } while(0)
#define IBF_CLRB_SetAnalogMode()      do { ANSELAbits.ANSA2 = 1; } while(0)
#define IBF_CLRB_SetDigitalMode()     do { ANSELAbits.ANSA2 = 0; } while(0)

// RA3 - A0 (A0_REG from GAL, directly read)
#define A0_TRIS                 TRISAbits.TRISA3
#define A0_PORT                 PORTAbits.RA3
#define A0_GetValue()           PORTAbits.RA3

// RA4 - IBF (Input Buffer Full from GAL)
#define IBF_TRIS                 TRISAbits.TRISA4
#define IBF_LAT                  LATAbits.LATA4
#define IBF_PORT                 PORTAbits.RA4
#define IBF_WPU                  WPUAbits.WPUA4
#define IBF_OD                   ODCONAbits.ODCA4
#define IBF_ANS                  ANSELAbits.ANSA4
#define IBF_GetValue()           PORTAbits.RA4
#define IBF_SetDigitalInput()    do { TRISAbits.TRISA4 = 1; } while(0)
#define IBF_SetDigitalOutput()   do { TRISAbits.TRISA4 = 0; } while(0)
#define IBF_SetPullup()          do { WPUAbits.WPUA4 = 1; } while(0)
#define IBF_ResetPullup()        do { WPUAbits.WPUA4 = 0; } while(0)
#define IBF_SetAnalogMode()      do { ANSELAbits.ANSA4 = 1; } while(0)
#define IBF_SetDigitalMode()     do { ANSELAbits.ANSA4 = 0; } while(0)
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

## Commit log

2026-02-24 Rearchitect host write timing with /SIG2 GAL clock
    Replace CLC1-based A0 latching and combinational IBF with GAL-registered
    outputs clocked by /SIG2 (inverted SIG2 via new U5 74AHCT1G14). This fixes
    write timing — data and address are now captured on the falling edge of PHI2
    (6502) or WRB (Z80), when all bus signals have been stable for the entire
    active phase.
    Key changes:
    - GAL: IBF and A0_REG are registered (load/hold mux), OBF is combinational
    SR-latch, AR removed, CLK_OUT moved to pin 9, A0_REG on pin 14
    - Firmware: CLC1 removed, host_get_a0() reads RA3 directly, IBF clear uses
    spin-wait for next clock edge, fixed hardcoded is_cmd in main loop
    - Hardware: Add U5 inverter, remove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
    [host.c, main.c, pins.h]
2026-02-26 GAL async reset for IBF clear, doc fixes, linting
    - PLD: Add AR product term for async IBF/A0_REG clear (fixes Z80 deadlock)
    - Firmware: Fix LATA init (OE_INB high at startup), simplify IBF clear
    - Firmware: Move IDATA remap functions from pins.h to host.c
    [PICkeeby.kicad_pcb, PICkeeby.kicad_sch]
2026-02-26 add license, update readme
    [PICkeeby.kicad_pcb, PICkeeby.kicad_sch]
